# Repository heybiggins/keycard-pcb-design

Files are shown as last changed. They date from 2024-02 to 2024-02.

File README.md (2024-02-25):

# keycard-pcb-design

## I built the PCB for this keyboard using:

https://docs.ergogen.xyz/

https://www.kicad.org/

https://jlcpcb.com/

## I followed these guides:

https://flatfootfox.com/ergogen-introduction/

https://youtu.be/UKfeJrRIcxw (Ben Vallack)

https://kbd.news/The-Japanese-duplex-matrix-1391.html

## I wrote about the experience:

https://heybiggins.com/keycard/

pcb_wiring

pcb_irl

pcb_soldered

keyboard_finished

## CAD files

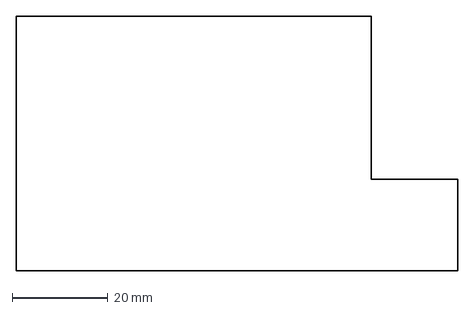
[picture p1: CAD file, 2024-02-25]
outlines/raw.dxf
92.0 x 53.0 mm

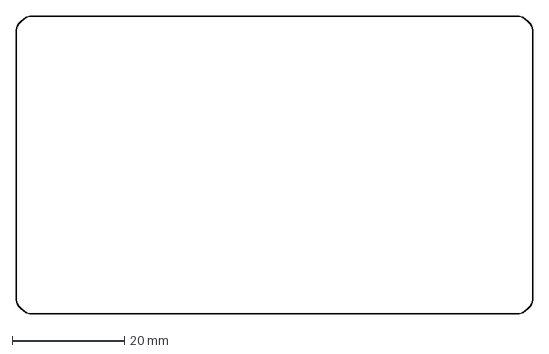
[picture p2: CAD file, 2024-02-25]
outlines/combo.dxf
92.0 x 53.0 mm

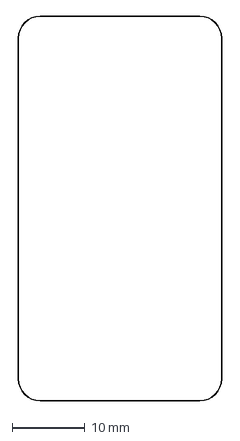
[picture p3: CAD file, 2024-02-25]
outlines/thumb_gap.dxf
28.0 x 53.0 mm

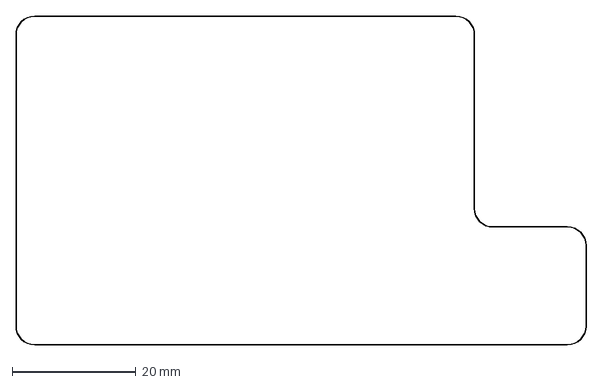
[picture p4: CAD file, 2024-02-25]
outlines/board.dxf
92.0 x 53.0 mm

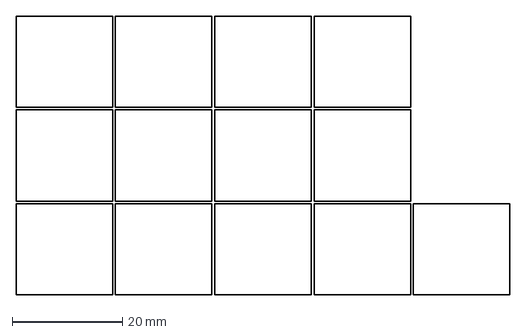
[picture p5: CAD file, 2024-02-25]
outlines/keys.dxf
89.5 x 50.5 mm

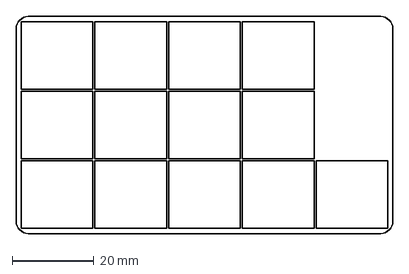
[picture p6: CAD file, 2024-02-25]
outlines/card.dxf
92.0 x 53.0 mm

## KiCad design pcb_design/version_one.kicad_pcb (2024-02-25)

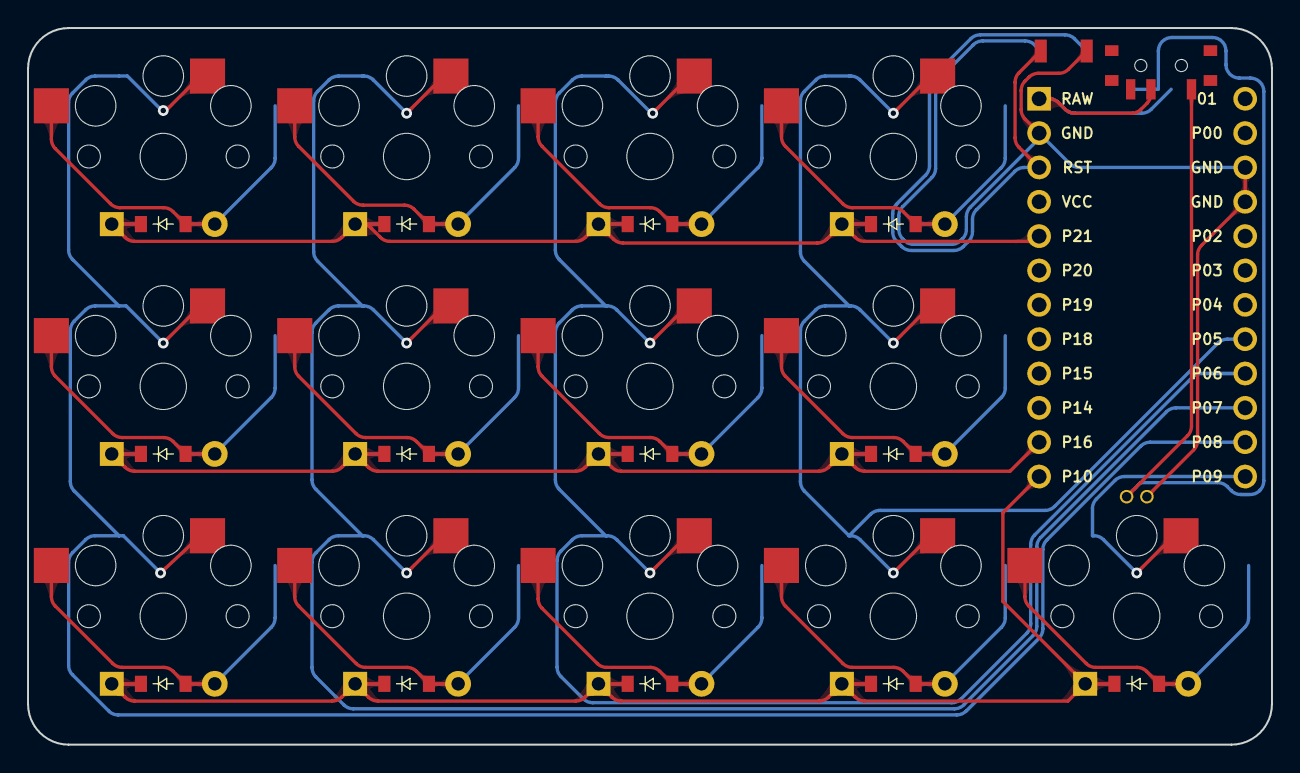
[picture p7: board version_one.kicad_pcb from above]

Board: 2 copper layers, 92.0 x 53.0 mm, 27 parts (0 on the bottom side), 22 nets.

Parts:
D1, D2, D3, D4, D5, D6, D7, D8, D9, D10, D11, D12, D13: ComboDiode
MCU1: ProMicro
S1, S2, S3, S4, S5, S6, S7, S8, S9, S10, S11, S12, S13: PG1350

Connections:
GND: MCU1.2, MCU1.15, MCU1.16
P5: MCU1.20, S10.1, S11.1, S12.1
P6: MCU1.21, S7.1, S8.1, S9.1
P7: MCU1.22, S4.1, S5.1, S6.1
P8: MCU1.23, S1.1, S2.1, S3.1
P9: MCU1.24, S13.1
P10: D1.1, D4.1, D7.1, D10.1, D13.1, MCU1.12
P16: D2.1, D5.1, D8.1, D11.1, MCU1.11
P21: D3.1, D6.1, D9.1, D12.1, MCU1.5
index_bottom: D10.2, S10.2
index_home: D11.2, S11.2
index_top: D12.2, S12.2
middle_bottom: D7.2, S7.2
middle_home: D8.2, S8.2
middle_top: D9.2, S9.2
pinky_bottom: D1.2, S1.2
pinky_home: D2.2, S2.2
pinky_top: D3.2, S3.2
ring_bottom: D4.2, S4.2
ring_home: D5.2, S5.2
ring_top: D6.2, S6.2
thumb_bottom: D13.2, S13.2

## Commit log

2024-02-25 Create footprints
2024-02-25 add kicad files
    [version_one.kicad_pcb]
2024-02-25 add footprints
2024-02-25 add ergogen outlines
    [board.dxf, card.dxf, combo.dxf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]
